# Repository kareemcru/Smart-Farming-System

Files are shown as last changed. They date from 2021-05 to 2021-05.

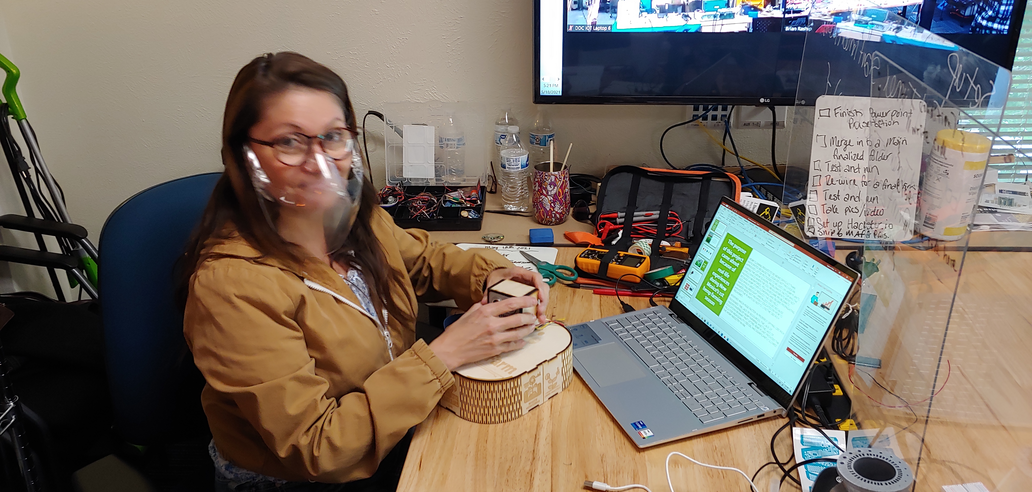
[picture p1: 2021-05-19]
20210518_172135.jpg

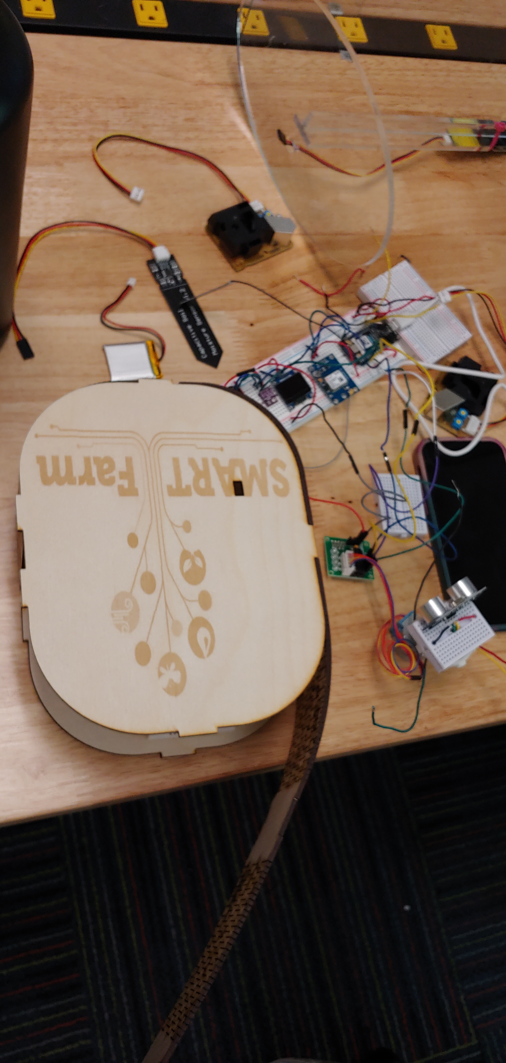
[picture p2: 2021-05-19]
20210518_083820.jpg

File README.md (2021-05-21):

# Smart-Farm-System
A **Smart Farm System** (SFS) with environmentally safe pest control; cost effective real-time monitoring; state-of-the art capabilities *Farmers* need to meet maximum yield year after year. *SmartTools* for overall *Product Quality*.

# Overview
The innovative **SFS** *alleviates* reduces the time and cost of the tedious **crucial** work farmers must do from one side of the globe to the other. This system is user friendly and covers any type of environment. 
The SFS communication capabilities extending across the globe with GPS real-time location data;smart device connectivity; **Cloud Commputing** utilizing WiFi via router or hotspot. Provides farmers with the peace of mind, by providing them access to crop status arround the clock from anywhere in the world. 
In comparison to other farming systems on the market, this **smart farming system** is a **tesla** because it's *Cutting Edge Technology* boosts ROI and farmer morale!

# Components/Details
* Particle Argon
* UltraSonic Component
* Adafruit Ultimate GPS Breakout
* Adafruit OLED display
* Seeed Grove Dust Sensor
* Adafruit BME 280
* Soil Moisture Sensor
* Stepper Motor
* Solar Cell
* Rechargeable Battery
* DFRobot 6 DOF Sensor - MPU6050

#Computing Tools
*Adobe Illustrator
*Safari
*Chrome
*Apple iPhone
*Android Phone
*Makercase.com
Adafruit.io
Github.com
Hackster.com
Zapier.com

# Parts/ Tools
* Metal Pole
* Pliers
* Wire Strippers
* Soldering Iron
* Hand Sander
* BreadBoard
* Wood
* Wire
* Paint
* Epilog Laser Cutter
* USB Thumb Drive

# Summary
The *overall* project of making this **Smart Farm System** began at 0830 on 11-May-2021 and is designed to aide farmers in *not only* the **health** of their crops, 
but the **security** and **sanctity** of their crops as well. **Stephanie Perea and Kareem Crum** worked *tirelessly* to implement the components in such a fashion that would
bring their vision for **hemp** farmers to *fruition. Stephanie handled the bulk of the **fabrication** for this project as well as the **power point presentation** and **component research**. Kareem handled the bulk of the **coding** for this project as well as the **Adafruit.IO dashboard**g and the **Github Project Repository**. Both Kareem and Stephanie contributed to **Hackster.io** and worked as a *team* smoothly and keeping a good working pace.  Collaborated on the overall project's *asthetics*. The project's completion date is 21-MAY-2021 with the conclusion ending with an online presentation with industry leaders.

The Smart Farming System houses a weather station and a plant monitoring system. The weather station is comprised of 2 components and a cloud- based website. The first component is the BME280 which is a temperature, humidity and pressure sensor. The second component is a monochrome I2C OLED Display unit with a 128 x 64 resolution dot matrix panel. The weather data can be accessed from anywhere in the world via Adafruit.io which provides real-time data on a crop’s environment and soil status. The plant monitoring system comprises of two components, a soil sensor and the Grove Particulate/Dust sensor. Both of these components are rather simple in both implementation and function; as well as, in the critical rolls they play in alleviating multiple burden off a farmers shoulders.
The soil sensor is implanted directly into the ground via stake, and gathers the moisture readings from the surrounding region in order to aid the farmer in detecting plant stress which affects a farmer's yield. 
The particulate/dust sensor sits within the wooden enclosure behind a living hinge which allows for ample air circultion for optimal pollen readings, all awhile protecting the component from the elements. The precision of these two components serve to aid the farmer in determining the overall environmental conditionsm be it in the soil or in the atmospheric surroundings of the region. Both components monitoring feeds are utilized through a user friendly, cloud computing interface known as Adafruit.IO dashboard which was crafted to be aesthetically pleasing and easy to understand.

The Smart Farming System also houses a security system and pest deterring system. One component fulfills the function of both systems at the same time. It is able to do so with the use of an Ultrasonic Sensor and a Stepper motor connected to an Argon microcontroller.
The Stepper motor serves as the mechanism provideing afull sweep of the full area the ultrasonic sensor is protecting. The step motor makes 180 degree turns continuously every 5 seconds. The magic happens when the Ultrasonic sensor is engaged! This advanced sensor, coupled with our innovative code and logic, sends out 8 pulses each 40 kH in frequency, to naturally deter pests within a half circle radius, with a 36-foot reach. Furthermore, the Ultrasonic sensor also has the capability to simultaneously count the amount of time between each, 8-pulse segment and a return pusle(s). The number of seconds assists in determinating the approximate location of an INTRUDER as well! This component will notify the farmer about any changes in location pulsing via an SMS text message through Zapier.com; as well as by changing the colors on the Adafruit.IO dashboard from purple to red.

We will now move on to vital functions that help the farmer know the status of the system! Second to last is the GPS and fall detection systems. The GPS functions are utilized in determining the location of the unit but this function is catered more towards large farm field owners. Furthermore, the GPS constantly populates a street map of real time coordinates on the Adafruit.IO dashboard. 
The fall detection system utilizes the MPU 6050 component in order to constantly give back data as to the orientation of the box. This data is expected to consistently give back the same date (primarily because the box stays in place). However, if the MPU reads a change in data on any of the axis planes (Z, X, Y), it will notify the farmer via SMS text message as well as changing the colors on the Adafruit.IO dashboard.

# Links
The link to our **Hackster.IO** is https://www.hackster.io/stephanie-and-kareem/smart-farming-system-3ad87e

The link to our **Adafruit.IO Dashboard** is  https://io.adafruit.com/Kareemcru/dashboards/smart-farming-system

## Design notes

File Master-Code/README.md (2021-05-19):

# Master-Code

A Particle project named Master-Code

## Welcome to your project!

Every new Particle project is composed of 3 important elements that you'll see have been created in your project directory for Master-Code.

#### ```/src``` folder:  
This is the source folder that contains the firmware files for your project. It should *not* be renamed. 
Anything that is in this folder when you compile your project will be sent to our compile service and compiled into a firmware binary for the Particle device that you have targeted.

If your application contains multiple files, they should all be included in the `src` folder. If your firmware depends on Particle libraries, those dependencies are specified in the `project.properties` file referenced below.

#### ```.ino``` file:
This file is the firmware that will run as the primary application on your Particle device. It contains a `setup()` and `loop()` function, and can be written in Wiring or C/C++. For more information about using the Particle firmware API to create firmware for your Particle device, refer to the [Firmware Reference](https://docs.particle.io/reference/firmware/) section of the Particle documentation.

#### ```project.properties``` file:  
This is the file that specifies the name and version number of the libraries that your project depends on. Dependencies are added automatically to your `project.properties` file when you add a library to a project using the `particle library add` command in the CLI or add a library in the Desktop IDE.

## Adding additional files to your project

#### Projects with multiple sources
If you would like add additional files to your application, they should be added to the `/src` folder. All files in the `/src` folder will be sent to the Particle Cloud to produce a compiled binary.

#### Projects with external libraries
If your project includes a library that has not been registered in the Particle libraries system, you should create a new folder named `/lib/<libraryname>/src` under `/<project dir>` and add the `.h`, `.cpp` & `library.properties` files for your library there. Read the [Firmware Libraries guide](https://docs.particle.io/guide/tools-and-features/libraries/) for more details on how to develop libraries. Note that all contents of the `/lib` folder and subfolders will also be sent to the Cloud for compilation.

## Compiling your project

When you're ready to compile your project, make sure you have the correct Particle device target selected and run `particle compile <platform>` in the CLI or click the Compile button in the Desktop IDE. The following files in your project folder will be sent to the compile service:

- Everything in the `/src` folder, including your `.ino` application file
- The `project.properties` file for your project
- Any libraries stored under `lib/<libraryname>/src`

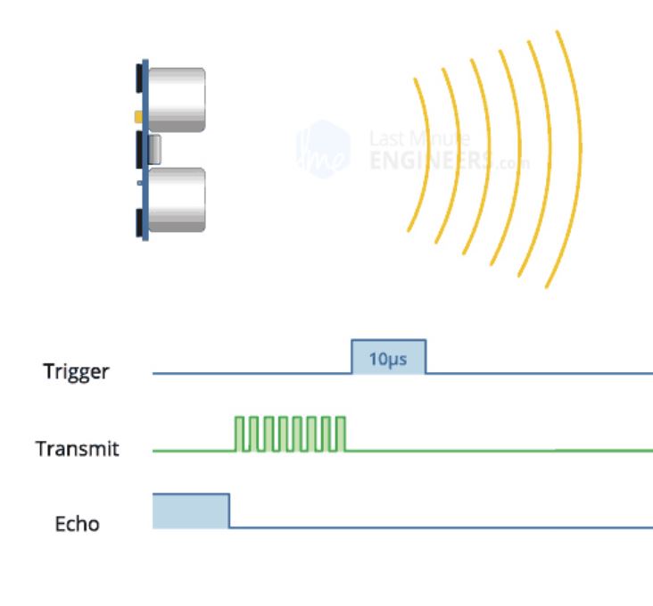
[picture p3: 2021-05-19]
ultrasonic graphic working.JPG

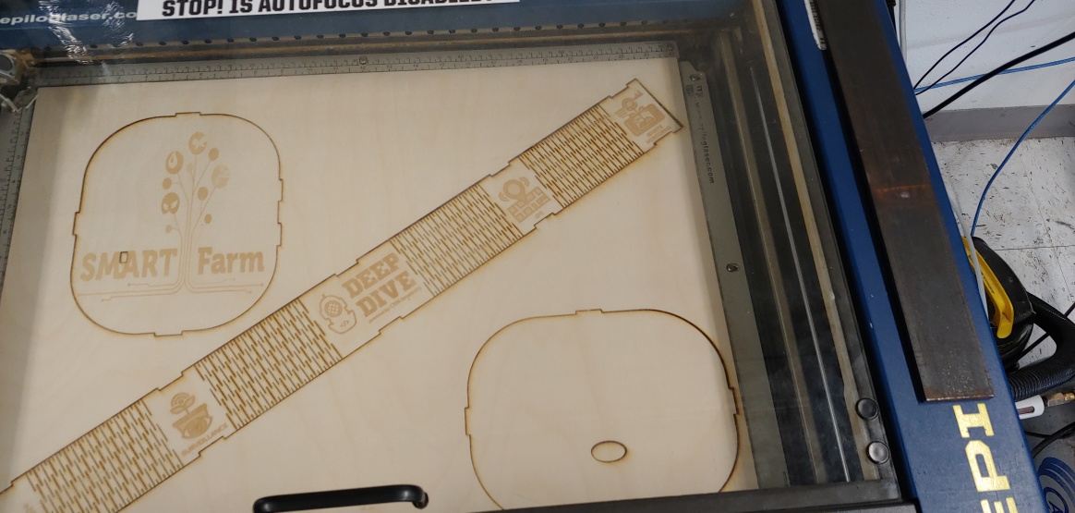
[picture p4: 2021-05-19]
20210517_161220_resized.jpg

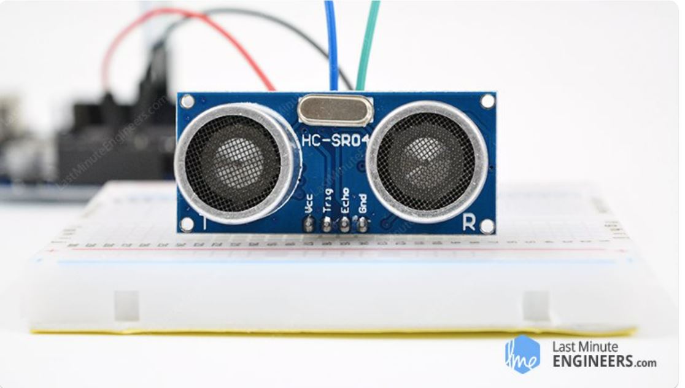
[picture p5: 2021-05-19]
Ultrasonic sensor.JPG

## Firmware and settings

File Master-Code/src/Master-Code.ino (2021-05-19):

/*
 * Project Master-Code
 * Description: The Smart Farming System Master Code
 * Author: Stephanie Perea and Kareem Crum
 * Date: 19-MAY-2021
 */
#include <TinyGPS++/TinyGPS++.h>
#include <Adafruit_MQTT.h>

#include "math.h"
#include "Adafruit_MQTT/Adafruit_MQTT.h" 
#include "Adafruit_MQTT/Adafruit_MQTT_SPARK.h" 
#include "Adafruit_MQTT/Adafruit_MQTT.h"
#include "Adafruit_SSD1306.h"
#include "Adafruit_GFX.h"
#include "Adafruit_BME280.h"
#include "Adafruit_Sensor.h"
#include "Particle.h"
#include "Stepper.h"
#include "credentials.h"

#define SCREEN_WIDTH 128 // OLED display width, in pixels
#define SCREEN_HEIGHT 64 // OLED display height, in pixels
#define OLED_RESET    D4 // Reset pin # (or -1 if sharing Arduino reset pin)
#define SCREEN_ADDRESS 0x3C ///< See datasheet for Address; 0x3D for 128x64, 0x3C for 128x32
#define XPOS 0
#define YPOS 1
#define echoPin D6 // attach pin D6 Arduino to pin Echo of HC-SR04
#define trigPin D7 //attach pin D7 Arduino to pin Trig of HC-SR04



//Global State
TCPClient TheClient;

//Adafruit BME class
Adafruit_BME280 bme;

//Adafruit OLED Class
Adafruit_SSD1306 display(OLED_RESET);

//Stepper Class
Stepper myStepper(2048, D5, D3, D4, D2);

//MQTT Client Class
Adafruit_MQTT_SPARK mqtt(&TheClient,AIO_SERVER,AIO_SERVERPORT,AIO_USERNAME,AIO_KEY); 

//TinyGPS++ Object
TinyGPSPlus gps;

//Feeds
Adafruit_MQTT_Publish Trigger = Adafruit_MQTT_Publish(&mqtt, AIO_USERNAME "/feeds/UltraSonic");
Adafruit_MQTT_Publish Satellites = Adafruit_MQTT_Publish(&mqtt, AIO_USERNAME "/feeds/Satellites");
Adafruit_MQTT_Publish GPS = Adafruit_MQTT_Publish(&mqtt, AIO_USERNAME "/feeds/Location");
Adafruit_MQTT_Publish Moist = Adafruit_MQTT_Publish(&mqtt, AIO_USERNAME "/feeds/SoilMoisture");
Adafruit_MQTT_Publish Pressure = Adafruit_MQTT_Publish(&mqtt, AIO_USERNAME "/feeds/Pressure");
Adafruit_MQTT_Publish Humid = Adafruit_MQTT_Publish(&mqtt, AIO_USERNAME "/feeds/Humidity");
Adafruit_MQTT_Publish Temp = Adafruit_MQTT_Publish(&mqtt, AIO_USERNAME "/feeds/Temperature");
Adafruit_MQTT_Publish Dust = Adafruit_MQTT_Publish(&mqtt, AIO_USERNAME "/feeds/DustSensor");
Adafruit_MQTT_Publish FallSense = Adafruit_MQTT_Publish(&mqtt, AIO_USERNAME "/feeds/Acceleration");


//Variable for BMe
float tempC;
float humidRH;
float pressPA;
float tempF;
float inHg;

//Variables for Soil Sensor
int soilSensor = A1;
int soilMoisturePercent; 
int soilMoistureValue; 

//Variables for DustSensor
unsigned long dustTime;
unsigned long duration;
unsigned long lastMQTT;
unsigned long lastPub;
int dustSensor = A0;
float dustSense;
unsigned long lowpulseoccupancy = 0;
float concentration = 0;
float ratio = 0;

//Variables for UltraSonic Sensor
long amount; // variable for the duration of sound wave travel
int distance; // variable for the distance measurement
bool intruder;

//Variables for Stepper and OLED
const int stepsRev = 2048;
int16_t stepperSpeed=15;
int16_t stepperSteps;

//Variables for GPS
const unsigned long PUBLISH_PERIOD = 120000;
const unsigned long SERIAL_PERIOD = 5000;
const unsigned long MAX_GPS_AGE_MS = 10000; // GPS location must be newer than this to be considered valid
const int UTC_offset = -6; 
unsigned long lastSerial = 0;
unsigned long lastPublish = 0;
unsigned long startFix = 0;
bool gettingFix = false;
char buffer[50];
uint8_t hr,mn,se,sat;
float lat,lon,alt;

//Variables for Acceleromotor
byte accel_x_h, accel_x_L;
int16_t accel_x;
float accelX;

byte accel_y_h, accel_y_L;
int16_t accel_y;
float accelY;

byte accel_z_h, accel_z_L;
int16_t accel_z;
float accelZ;
float accelTot;

bool MPUfall = false;
float MPUValue = 0.0;
const float fall = 1.0;

SYSTEM_MODE(SEMI_AUTOMATIC);

// setup() runs once, when the device is first turned on.
void setup() 
{
  // Put initialization like pinMode and begin functions here.
  pinMode(soilSensor, INPUT);
  pinMode(dustSensor, INPUT);
  pinMode(trigPin, OUTPUT); // Sets the trigPin as an OUTPUT
  pinMode(echoPin, INPUT); // Sets the echoPin as an INPUT

  dustTime = millis();

  Serial.begin(9600);

//I2C Setup
  Wire.begin();

  Wire.beginTransmission(0x68);

  Wire.write(0x6B);
  Wire.write(0);

  Wire.endTransmission(true);

//GPS Setup
	Serial1.begin(9600);
	startFix = millis();
	gettingFix = true;

	Serial.println(F("DeviceExample.ino"));
	Serial.println(F("A simple demonstration of TinyGPS++ with an attached GPS module"));
	Serial.print(F("Testing TinyGPS++ library v. ")); 
	Serial.println(TinyGPSPlus::libraryVersion());
	Serial.println(F("by Mikal Hart"));
	Serial.println();

	//OLED Setup
	display.begin(SSD1306_SWITCHCAPVCC, 0x3C);
	helloWorld();
	Serial.printf("Hello World \n");

  bool status;
  status = bme.begin(0x76);
  myStepper.setSpeed(15);
  myStepper.step(0);

  Serial.printf("Connecting to Internet \n");
  WiFi.connect();
  while(WiFi.connecting()) 
  {
    Serial.printf(".");
    delay(100);
  }
  Serial.printf("\n Connected!!!!!! \n");

  //UltraSonic Sensor Setup
  Serial.println("Ultrasonic Sensor HC-SR04 Test"); // print some text in Serial Monitor
  Serial.println("with Argon");

}

// loop() runs over and over again, as quickly as it can execute.
void loop()
{
  // The core of your code will likely live here.
  codingFunction();
  printValues();
  adafruitPublish();
  MQTT_connect();
}

void helloWorld() 
{
	display.clearDisplay();
	display.setTextSize(1);
	display.setTextColor(WHITE);
	display.setCursor(20,5);
	display.println("GPS Initializing");
	display.display();
}

void codingFunction()
{

  //Code for Stepper Motor
    myStepper.setSpeed(7);
    myStepper.step(1024);
    delay(2000);
    myStepper.step(-1024);
    delay(2000);

  //Code for Dust Sensor
  duration = pulseIn(dustSensor, LOW);
  lowpulseoccupancy = lowpulseoccupancy + duration;
  if ((millis()-dustTime) >= 30000)
  {
    ratio = lowpulseoccupancy/(30000*10.0);
    concentration = 1.1*pow(ratio,3)-3.8*pow(ratio,2)+520*ratio+0.62;
    if(concentration > 1){
      dustSense = concentration;
    }
    lowpulseoccupancy = 0;
    dustTime = millis();
  }
  
  //Code for Soil Sensor
  soilMoistureValue = analogRead(soilSensor);
  Serial.printf("Soil moisture is %i\n", soilMoistureValue);
  soilMoisturePercent = map(soilMoistureValue, 1800, 3500, 100, 0);
 
 //Code for UltraSonic Sensor
  digitalWrite(trigPin, LOW);
  delayMicroseconds(2);
  digitalWrite(trigPin, HIGH);
  delayMicroseconds(10);
  digitalWrite(trigPin, LOW);
  
  // Reads the echoPin, returns the sound wave travel time in microseconds
  amount = pulseIn(echoPin, HIGH);
  Serial.println("The Data is:");
  // Calculating the distance
  distance = amount * 0.034 / 2; // Speed of sound wave divided by 2 (go and back)
  if(distance <=96)
  {
    intruder = true;
    adafruitPublish();
  }

 //Code for BME
  tempC = bme.readTemperature();
  tempF = map(tempC,0.0,100.0,32.0,212.0);
  pressPA = bme.readPressure();
  inHg = pressPA/3386.389;
  humidRH = bme.readHumidity();
  
  //Code for Acceleromotor
  float accelZ, accelX, accelY;
  delay(1000);
  findAcceleration();
  
  Wire.requestFrom(0x68, 6, true);
  accel_x_h = Wire.read();
  accel_x_L = Wire.read();
  accel_x = accel_x_h << 8 |accel_x_L;
  accelX = accel_x / 15000.0;
  Serial.printf("X-axis acceleration is %0.2f\n", accelX);

  accel_y_h = Wire.read();
  accel_y_L = Wire.read();
  accel_y = accel_y_h <<8 | accel_y_L;
  accelY = accel_y / 16000.0;
  Serial.printf("Y-axis acceleration is %0.2f\n", accelY);

  accel_z_h = Wire.read();
  accel_z_L = Wire.read();
  accel_z = accel_z_h << 8 | accel_z_L;
  accelZ = accel_z / 15250.0;
  Serial.printf("Z-axis acceleration is %0.2f\n", accelZ);
  
  accelTot = sqrt(pow(accelX,2)+pow(accelY,2)+pow(accelZ,2));
  Serial.printf("Accel Total Value: %0.2f \n", accelTot);

  if(!MPUfall) 
  {
    MPUValue = accelTot;
    MPUfall = (MPUValue > fall);
    Serial.printf("MPU Value is %0.2f\n", MPUValue);
  }

  //Code for GPS
   while (Serial1.available() > 0)
  {
    if (gps.encode(Serial1.read()))
	 { 
      displayInfo();
   }
  }
  delay(1000);

}

void findAcceleration()
{

  Wire.beginTransmission(0x68);
  Wire.write(0x3B);
  Wire.endTransmission(false);

}

void displayInfo()
{
	float lat,lon,alt;
	uint8_t hr,mn,se,sat;
	if (millis() - lastSerial >= SERIAL_PERIOD)
	{
		lastSerial = millis();

		char buf[128];
		if (gps.location.isValid() && gps.location.age() < MAX_GPS_AGE_MS) 
		{
			lat = gps.location.lat();
			lon = gps.location.lng(); 
			alt = gps.altitude.meters();
			hr = gps.time.hour();
			mn = gps.time.minute();
			se = gps.time.second();
			sat = gps.satellites.value();

			if(hr > 7) 
			{
				hr = hr + UTC_offset;
			}
			else 
			{
				hr = hr + 24 + UTC_offset;
			}
			Serial.printf("Time: %02i:%02i:%02i --- ",hr,mn,se);
			Serial.printf("lat: %f, long: %f, alt: %f \n", lat,lon,alt);
			if (gettingFix) 
			{
				gettingFix = false;
				unsigned long elapsed = millis() - startFix;
				Serial.printlnf("%lu milliseconds to get GPS fix", elapsed);
			}
			display.clearDisplay();
			display.setCursor(0,0);
			display.printf("Time: %02i:%02i:%02i \n",hr,mn,se);
			display.printf("lat  %f \nlong %f \nalt %f\n", lat,lon,alt);
			display.printf("satelites %i", sat);
			display.display();
      createEventPayload(lat, lon, alt, sat);
    }
    else 
		{
			strcpy(buf, "no location");
			if (!gettingFix) 
			{
				gettingFix = true;
				startFix = millis();
			}
		}
	}

}

void createEventPayload(float jlat, float jlon, float jalt, int sat)
{
  sprintf(buffer, "{\"lat\":%0.6f,\"lon\":%0.6f,\"ele\":%0.2f}", jlat, jlon, jalt); 
  
}

void printValues() 
{
    Serial.printf("Temperature = %f\n", tempF);
    Serial.print(bme.readTemperature());
    Serial.println(" *F");
    
    Serial.printf("Pressure = %f\n", inHg);
    Serial.print(bme.readPressure());
    Serial.println(" hPa");

    Serial.printf("Humidity = %f\n", humidRH);
    Serial.print(bme.readHumidity());
    Serial.println(" %");

    Serial.print("Distance: ");
    Serial.print(distance);
    Serial.println("cm");
    
    Serial.printf("Moist: %i %%\n", soilMoisturePercent);
    Serial.printf("Dust: %0.2f\n", dustSense);

    Serial.println();
}

void adafruitPublish()
{
    //Code for Adafruit.IO
    if(intruder)
    {
      Trigger.publish(distance);
      intruder = false;
    }
    if((millis()-lastPub > 30000)) 
    {
      if(mqtt.Update()) 
      {
        Serial.printf("Publishing %s\n", buffer);
        GPS.publish(buffer);
        Moist.publish(soilMoisturePercent);
        Temp.publish(tempF);
        Humid.publish(humidRH);
        Dust.publish(dustSense);
        Pressure.publish(inHg);  
        Satellites.publish(sat);
        if(MPUfall)
        {
          FallSense.publish(MPUValue);
          Serial.printf("MPU Fell %0.2f\n", MPUValue);
          MPUfall = false;
          MPUValue = 0.0;
        }
      } 
      lastPub = millis();
    }
}

void MQTT_connect() 
{
  int8_t ret;
 
  // Stop if already connected.
  if (mqtt.connected()) {
    return;
  }
 
  Serial.print("Connecting to MQTT... ");
 
  while ((ret = mqtt.connect()) != 0) { // connect will return 0 for connected
       Serial.println(mqtt.connectErrorString(ret));
       Serial.println("Retrying MQTT connection in 5 seconds...");
       mqtt.disconnect();
       delay(5000);  // wait 5 seconds
  }
  Serial.println("MQTT Connected!");
    // Ping MQTT Broker every 2 minutes to keep connection alive
  if ((millis()-lastMQTT)>120000) 
  {
      Serial.printf("Pinging MQTT \n");
      if(! mqtt.ping()) {
        Serial.printf("Disconnecting \n");
        mqtt.disconnect();
      }
      lastMQTT = millis();
  }
}

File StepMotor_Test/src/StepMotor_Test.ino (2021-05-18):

/*
 * Project L16_05_StepperGyro
 * Description: Wire stepper motor and move motor 2 rotations clockwise, pause, move 1 rotation counter-clockwise, repeat
 * Author:Stephanie Perea
 * Date:05/16/2021
*/

#include <math.h>
#include <Stepper.h>


//int16_t myStepper;
int16_t stepper_in1 = D5; //variable to store info from IN1
int16_t stepper_in2 = D4; //variable to store info from IN2
int16_t stepper_in3 = D3; //variable to store info from IN3
int16_t stepper_in4 = D2; //variable to store info from IN4 
int16_t stepperSpeed=15;
int16_t stepperSteps;
int16_t spr=2048;
Stepper myStepper (2048, D5, D3, D4, D2);

SYSTEM_MODE(SEMI_AUTOMATIC);
// setup() runs once, when the device is first turned on.
void setup() 
{
  myStepper.step(0);
}

// loop() runs over and over again, as quickly as it can execute.
void loop()
 {
myStepper.setSpeed(15);
myStepper.step(1024);
delay(2000);
myStepper.step(-1024);
delay(2000);
 

}

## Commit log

2021-05-14 The Replacement of the bad files
    [Smart-Farm-SystemFRITZ.fzz, ultrasonicSensorFritz.fzz]
2021-05-14 BME and Soil Sensor
    [Smart-Farm-SystemFRITZ.fzz]
2021-05-14 Dust Sensor Test
2021-05-17 replaced code with correct step motor code
    [StepMotor_Test.ino]
2021-05-17 Updating the Main Test Code W/ Stepper, and Adafruit.IO
2021-05-17 Setting up Test code for the Acceleromotor
2021-05-18 Fixing the Stepper Motor
    [Main_Test_Code.ino, StepMotor_Test.ino]
2021-05-18 Adding UltraSonic and Acceleromotor to Adafruit.IO
2021-05-19 powerpoint presentation
2021-05-19 Adding the MPU6050 in FRITZ and updating Code
    [Smart-Farm-SystemFRITZ.fzz]
2021-05-19 Adding the final touches (UltraSonic to Zapier)
2021-05-19 photos and Adobe Illustrator enclosure box files
2021-05-20 final PowerPoint Presentation
2021-05-20 Finishing the Powerpoint, waiting on Video Demo
